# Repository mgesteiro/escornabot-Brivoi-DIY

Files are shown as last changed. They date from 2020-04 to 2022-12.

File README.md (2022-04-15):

# Escornabot Brivoi Audacius (DIY)
My own update to some parts of the [Escornabot project](https://github.com/escornabot) started during the COVID-19 lockdown.

* **[3D](3D/):** Inspired in the genius work and lessons from [Xoan](https://github.com/xoan?tab=repositories&q=escornabot), I updated the **Brivoi Audacius (or DIY)** models to the last version of [FreeCAD](https://freecadweb.org) (v0.19), using exclusively the **Part-Design workbench** and including some minor changes to suit my own personal needs and issues (that may be useful for others too).

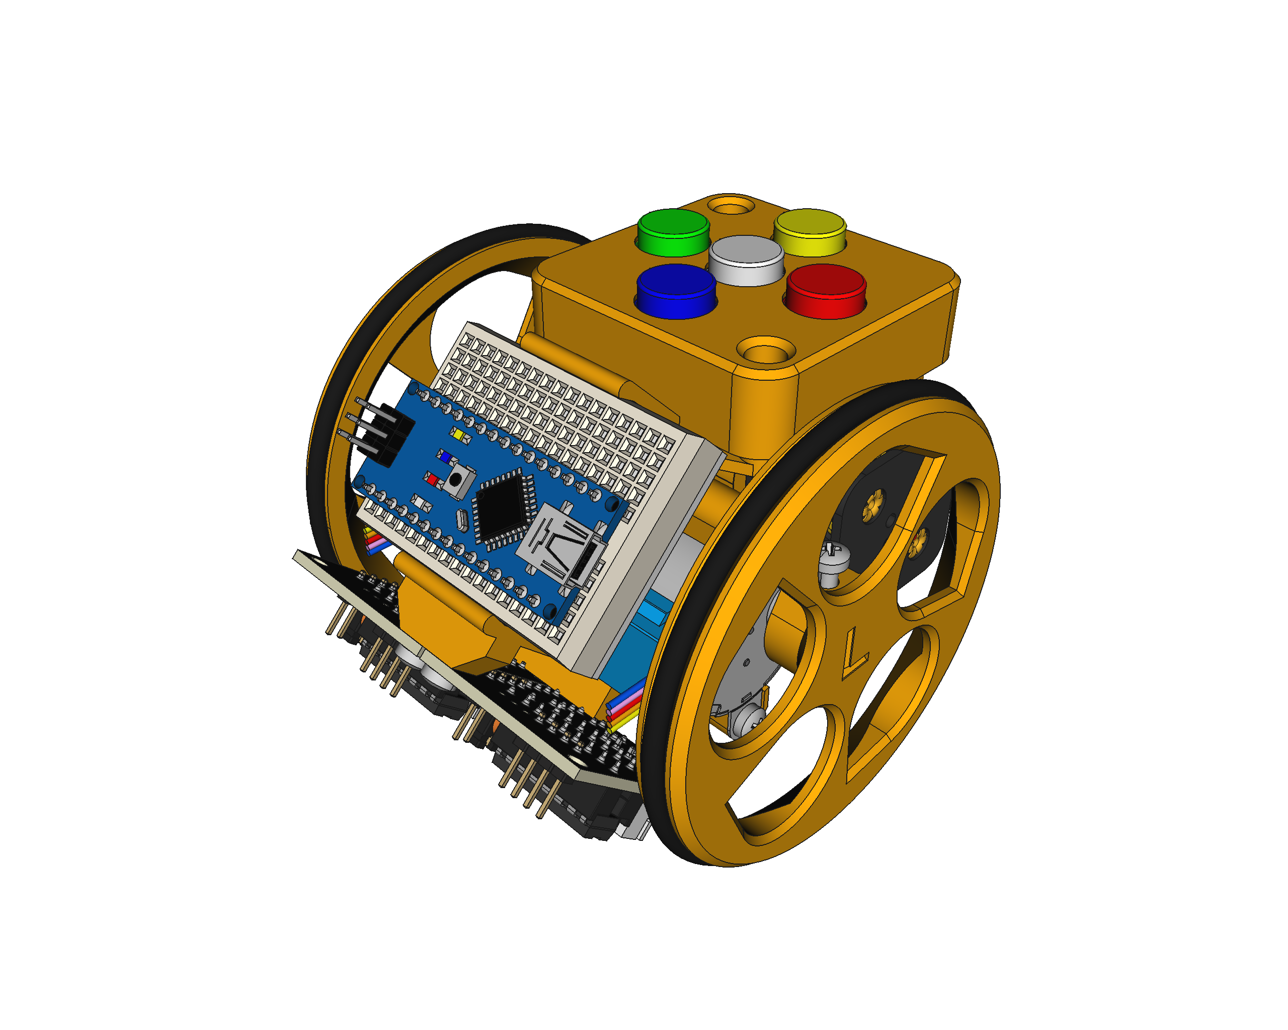
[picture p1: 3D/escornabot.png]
Escornabot
    

* **Electronics:** Everything related to the electronic part of the robot
    * **[Connections](electronics/connections/):** main schematic (done with [Fritzing](https://fritzing.org)).
    * **[Bluetooth Lower Energy](electronics/bluetooth/):** schematic, control App and firmware.

    Connections
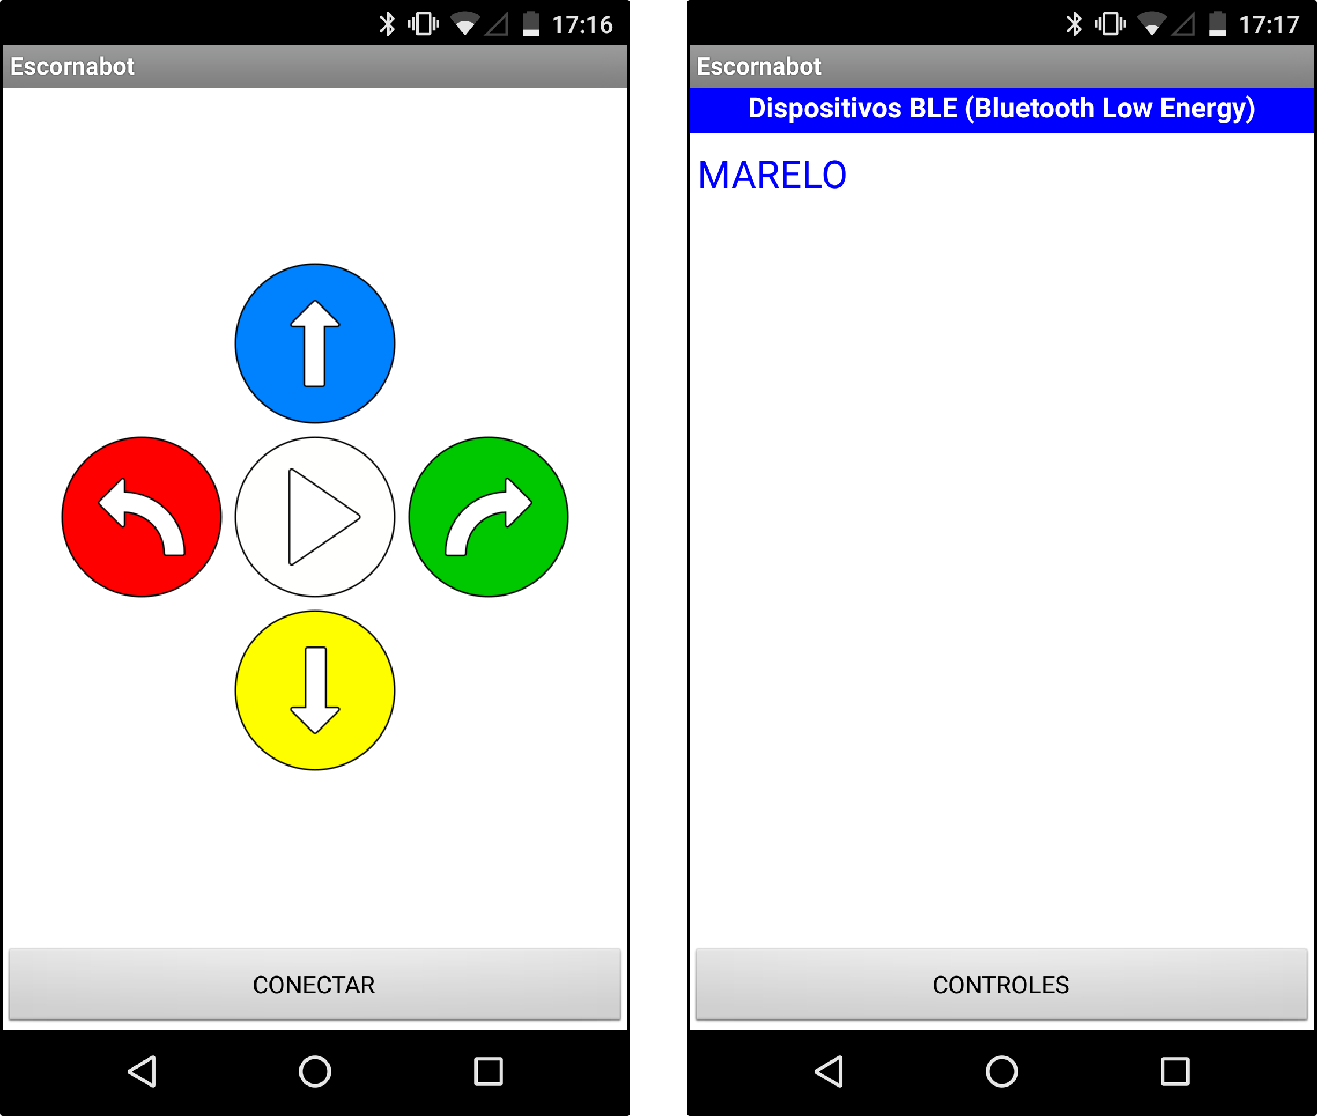
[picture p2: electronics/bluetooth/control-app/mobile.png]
BluetoothApp
    

## LICENSE

This work is licensed under the [GNU General Public License v3.0](LICENSE-GPLV30). All media and data files that are not source code are licensed under the [Creative Commons Attribution 4.0 BY-SA license](LICENSE-CCBYSA40).

More information about licenses in [Opensource licenses](https://opensource.org/licenses/) and [Creative Commons licenses](https://creativecommons.org/licenses/).

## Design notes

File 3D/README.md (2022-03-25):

# Escornabot Brivoi-DIY - 3D models

Updated 3D models of the **Escornabot Brivoi-DIY** to the last version of [FreeCAD](https://freecadweb.org) (v0.19), using exclusively the **Part-Design workbench** and including some minor changes to suit my own personal needs and issues (explained below), that may be useful to others too.

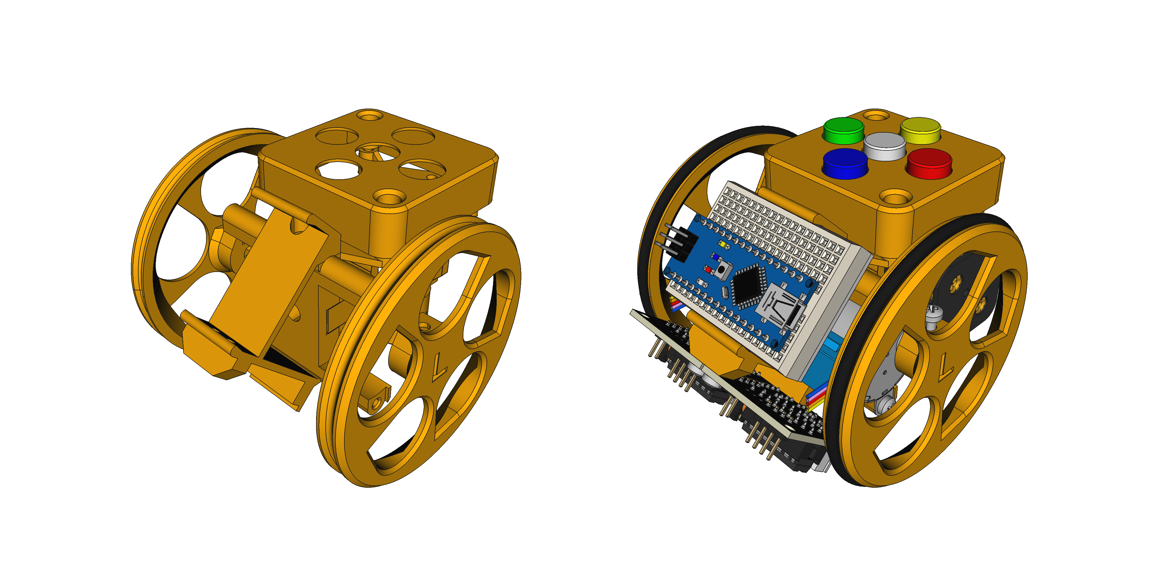
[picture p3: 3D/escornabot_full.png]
Escornabot

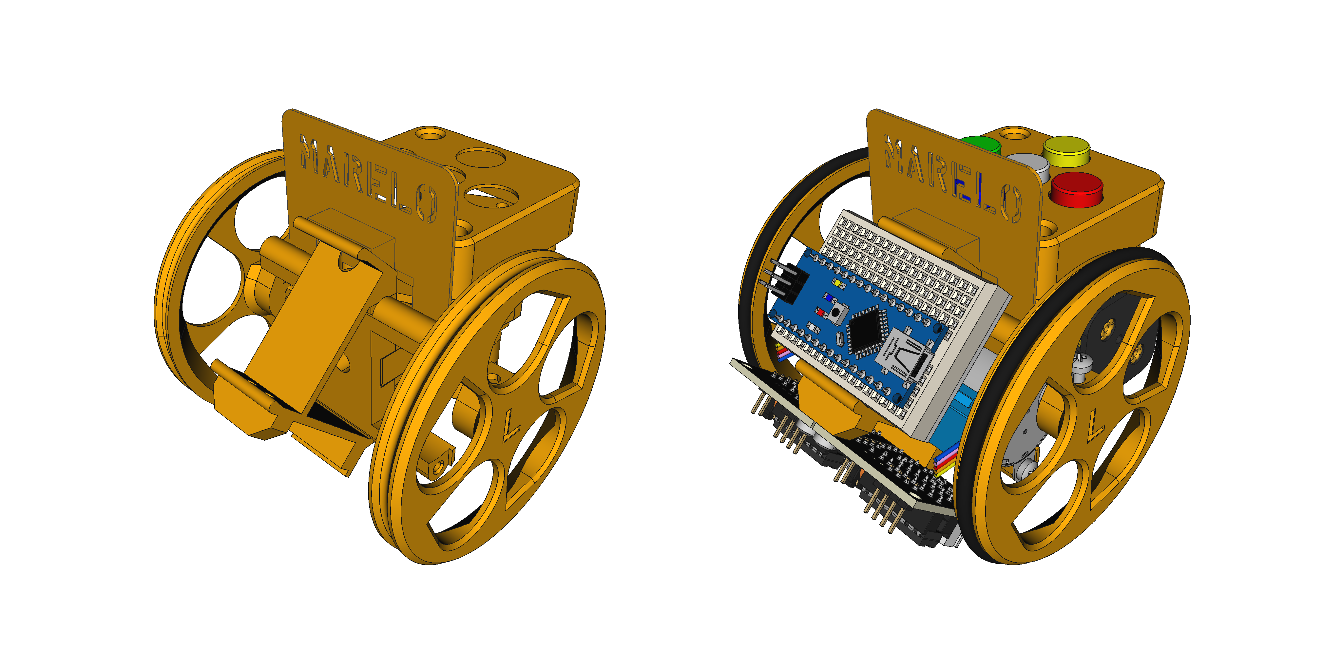
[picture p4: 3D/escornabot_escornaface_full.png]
Escornabot


* Now with a full assembly file (for the [Assembly4 FreeCAD workbench](https://wiki.freecadweb.org/Assembly4_Workbench)): **[escornabot.FCStd](escornabot.FCStd)**
* Additional non printable 3D parts in the `parts` folder
* STL files already generated and ready to use

### Battery bracket
New v-shaped joint for the motor bracket (borrowed from [Xoan](https://github.com/xoan?tab=repositories&q=escornabot)). Added configuration params to better fit different battery holder dimensions as I've found important differences.
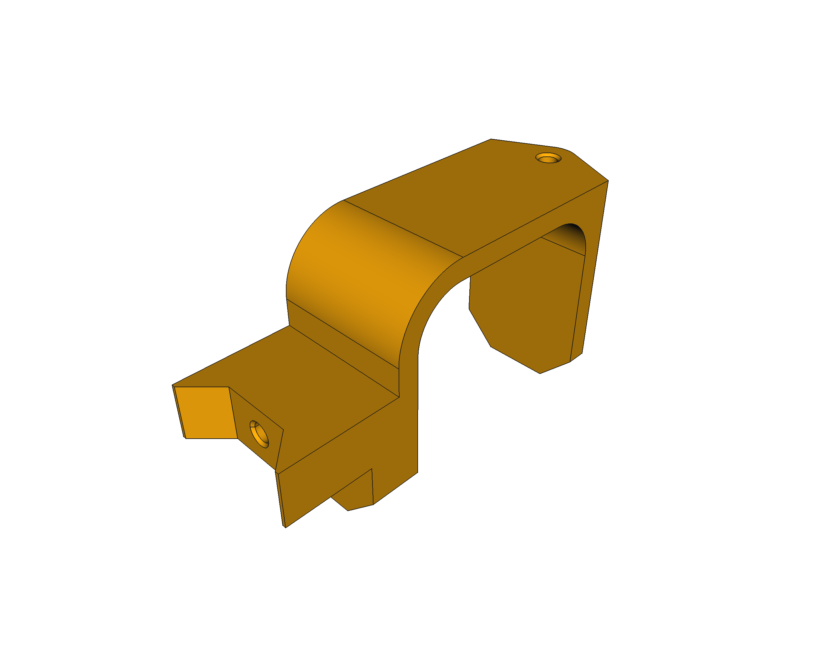
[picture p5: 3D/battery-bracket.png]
battery-bracket


### Motor bracket
Updated connection joint to the battery bracket: easier, simpler and more robust. Additional support for the stepper motor tabs.
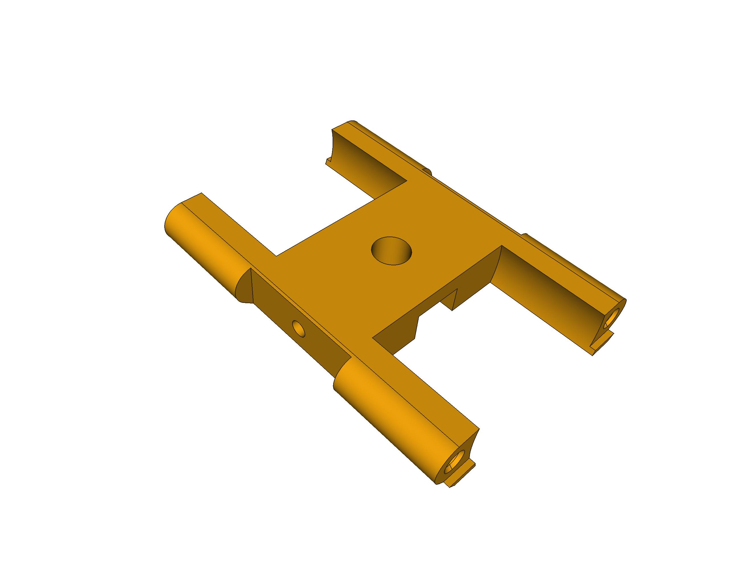
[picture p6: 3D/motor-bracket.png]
motor-bracket


### Keypad holder
Thinner. Added estructural support for the screw holders: easier to print and more robust.
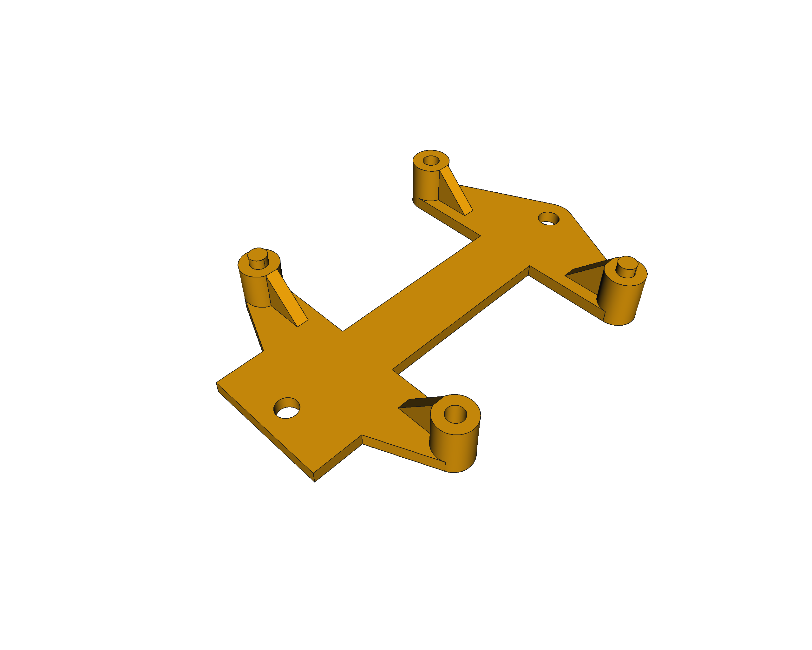
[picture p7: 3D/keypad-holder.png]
keypad-holder


### Board bracket
Converted to Part-Design workbench and updated supports for the stepper driver boards that should not move now.

* MiniBread Board 170 contacts by Robotdyn **without notches** (not available anymore)
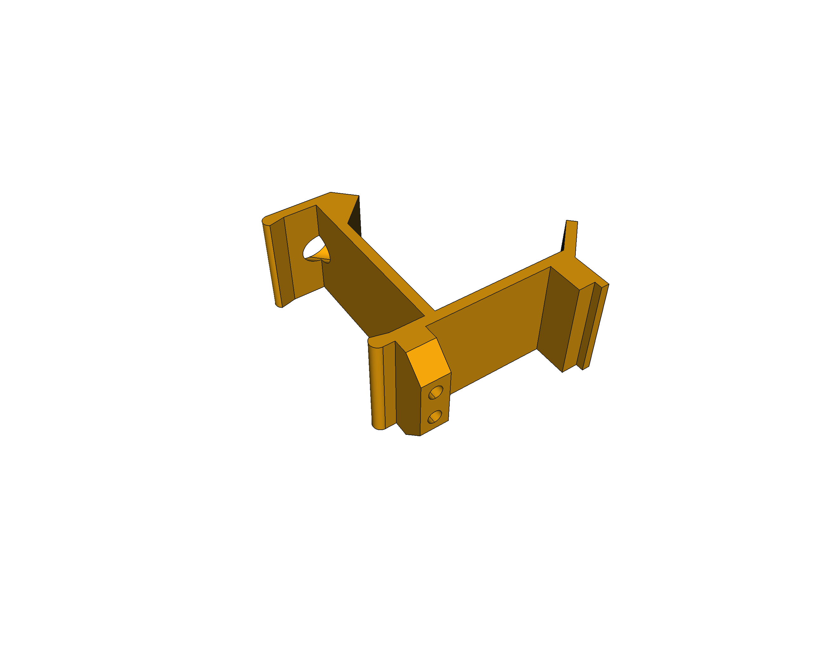
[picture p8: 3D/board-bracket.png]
board-bracket
	

* MiniBread Board 170 contacts with notches (more common)
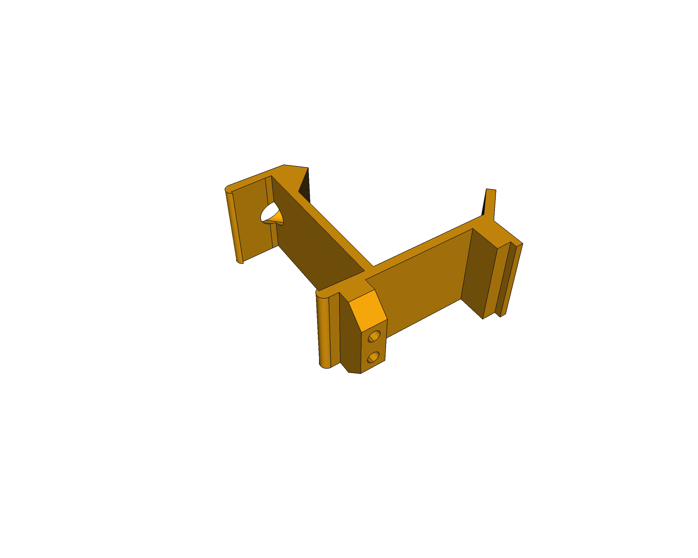
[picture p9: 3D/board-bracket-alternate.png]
board-bracket-alternate
	

### Ball caster and Ball caster battery
Added configuration params (e.g. ball diameter) and converted to Part-Design workbench.
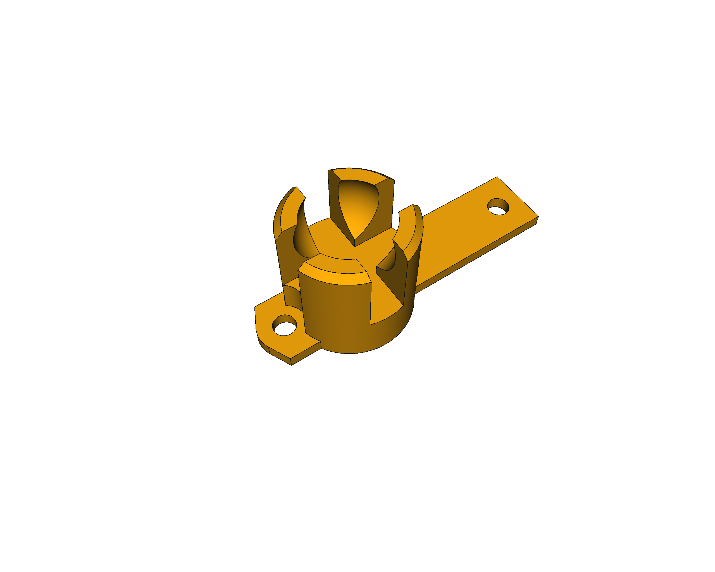
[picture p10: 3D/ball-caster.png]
ball-caster


With support for fifth HR06/AA 1.2V NiMH battery
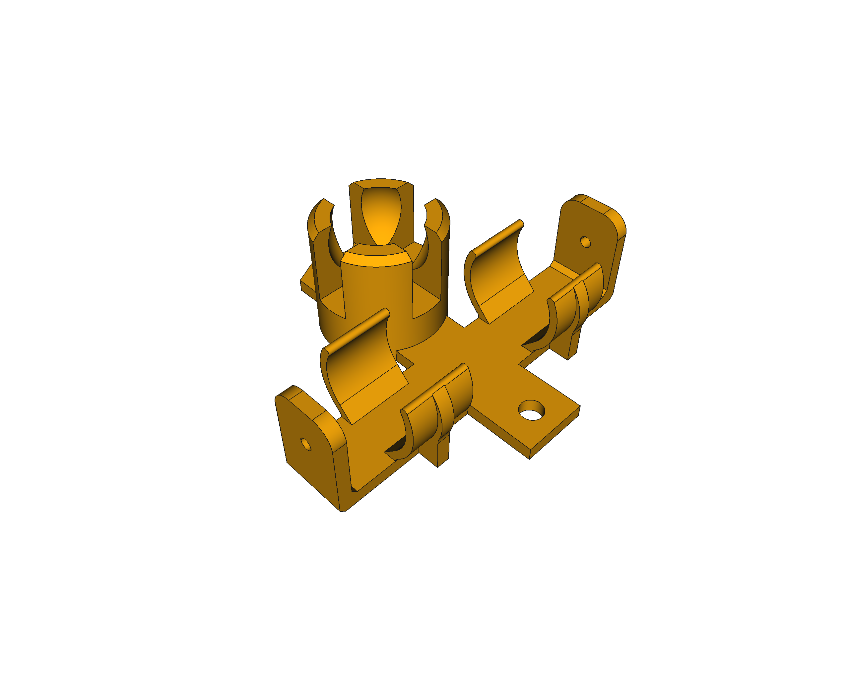
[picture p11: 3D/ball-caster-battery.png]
ball-caster-battery


### Switch holder
Converted to Part-Design workbench and redesigned.
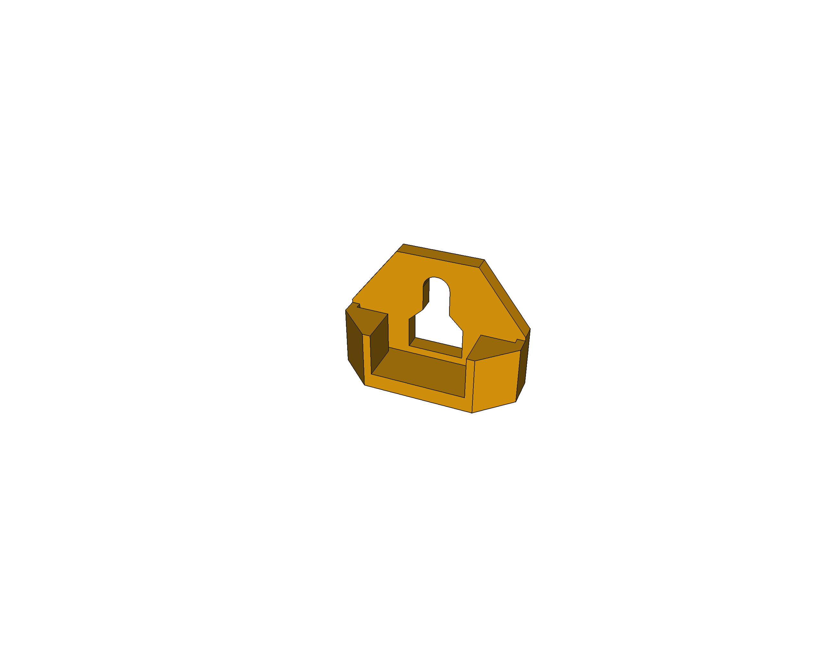
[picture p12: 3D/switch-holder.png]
switch-holder


### Wheels
Circular bed for the o-ring (no more "v"). Updated "L" and "R" letters and dimensions of some of the holes. Converted to Part-Design only. Available [base wheel](wheel-base.FCStd) ready to be customized.
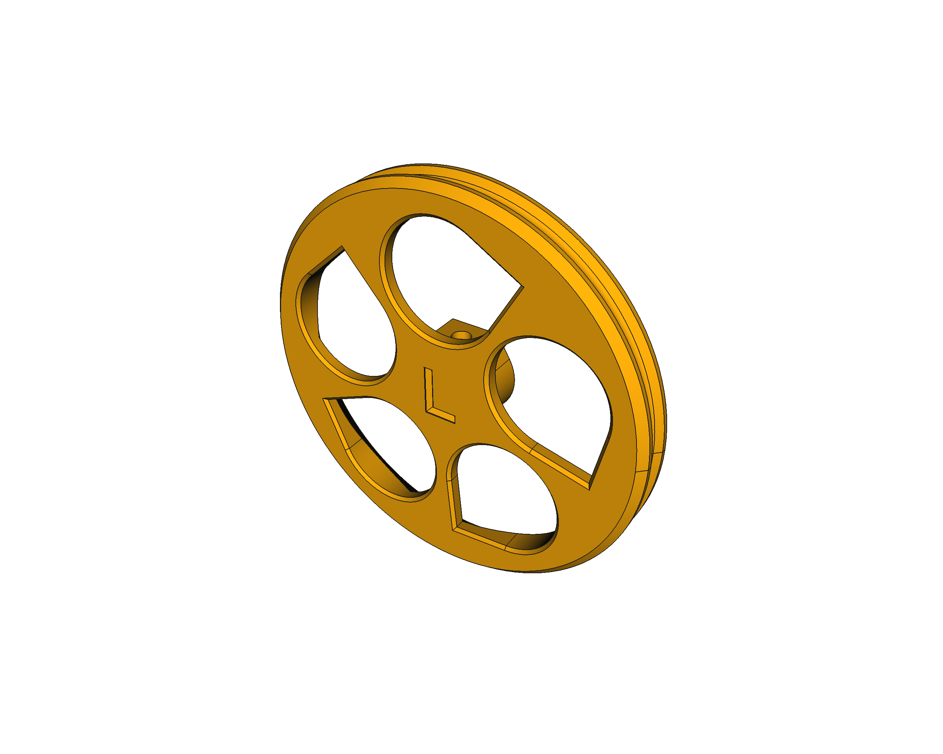
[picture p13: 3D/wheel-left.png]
wheel-left

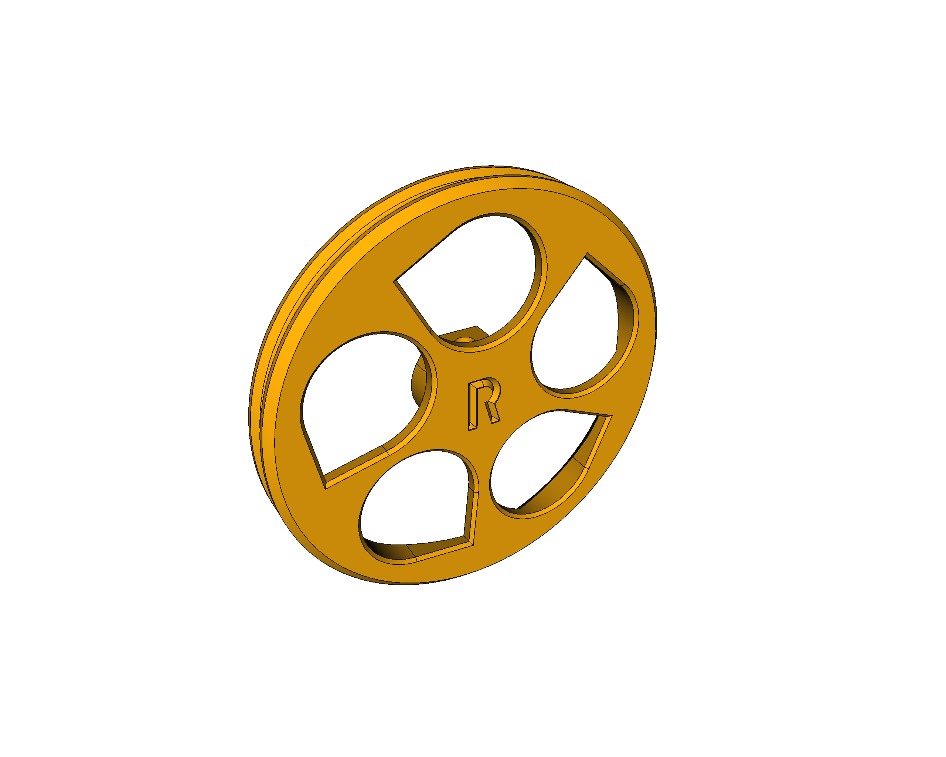
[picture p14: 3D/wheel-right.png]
wheel-right


### Keypad cover
This one is new, for [my own Ki-CAD keyboard](https://github.com/mgesteiro/escornakeypad) with B3F-40xx buttons and caps. Round corners, finally!
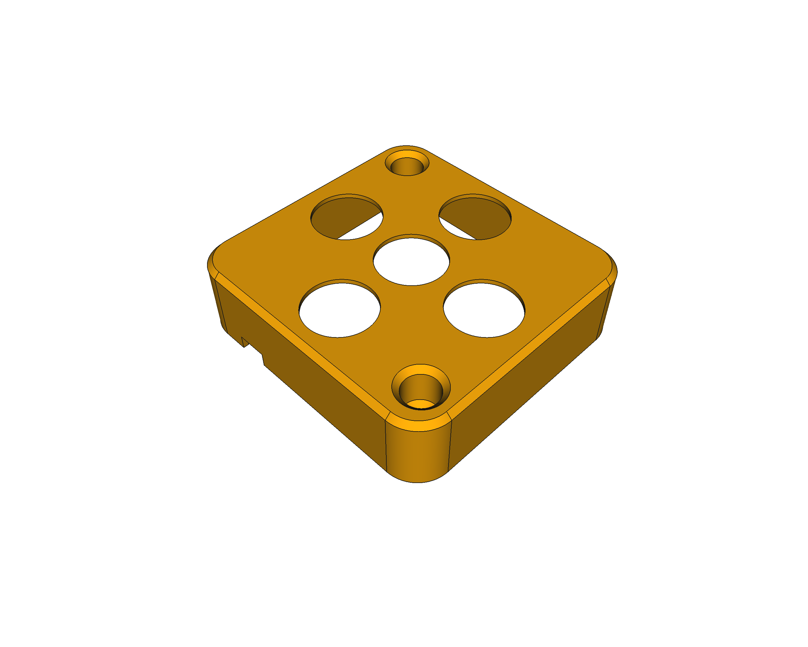
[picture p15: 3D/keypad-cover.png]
keypad-cover


## Extras
I made a couple of extra models:

### Escornaface
A piece to customize your Escornabot: put your name (or whatever you want).
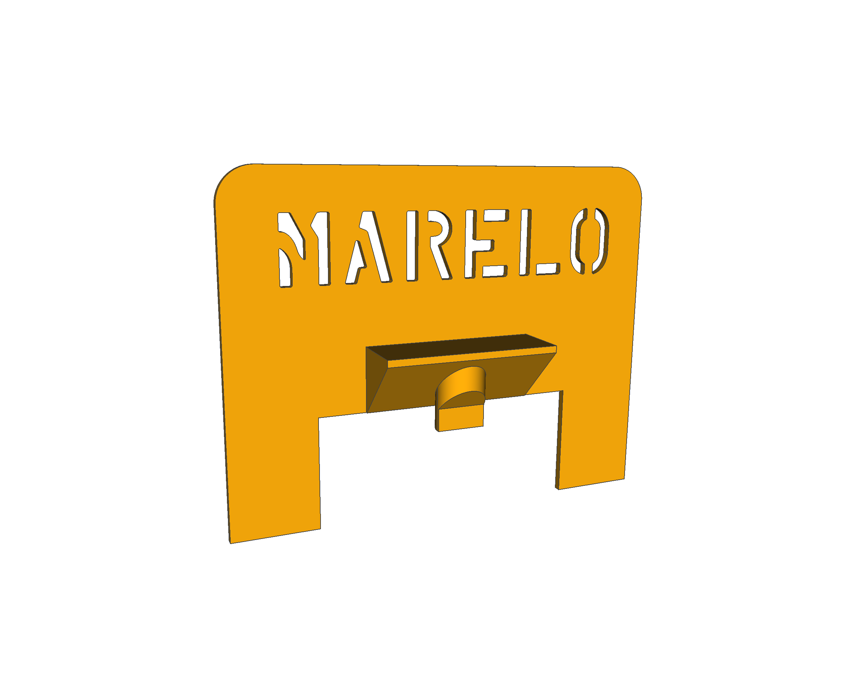
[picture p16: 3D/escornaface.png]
escornaface


### Battery bracket *Escornabot Pintor Kit*
A battery holder with pre-drilled holes to support the [Escornabot Pintor Kit](https://github.com/einsua/Escornabot_Pintor_Kit)
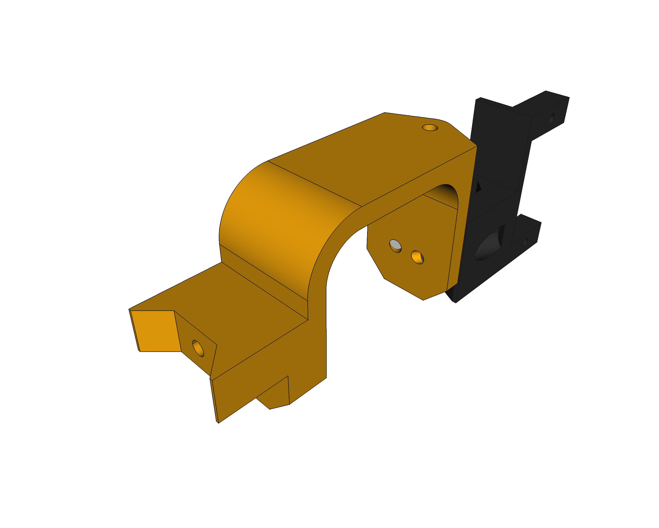
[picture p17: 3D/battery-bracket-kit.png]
battery-bracket-kit


### Ogaki CPU holder
In case you have an Abierto's Ogaki Escornabot: use instead of the **keypad holder** and **board bracket**.
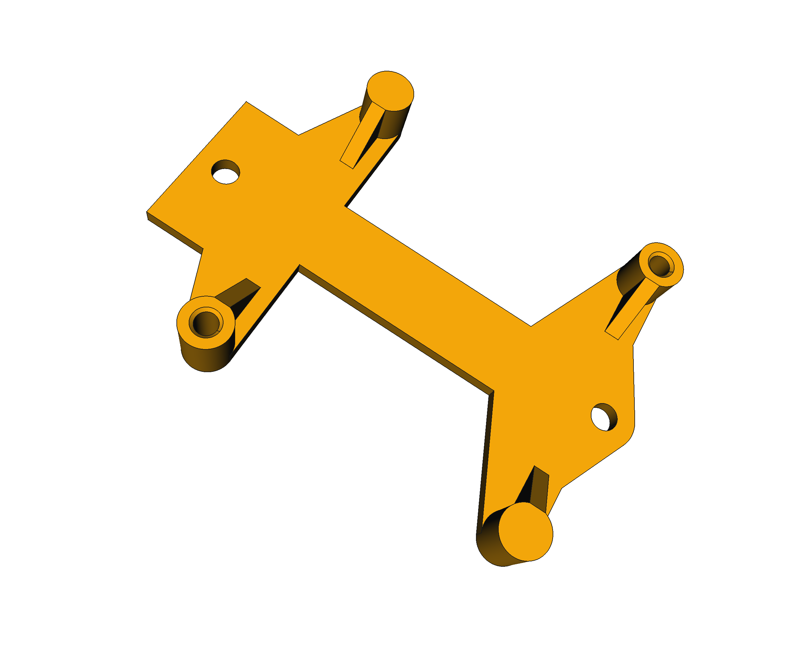
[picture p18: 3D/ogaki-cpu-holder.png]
ogaki-cpu-holder


## LICENSE

This work is licensed under the [GNU General Public License v3.0](../LICENSE-GPLV30). All media and data files that are not source code are licensed under the [Creative Commons Attribution 4.0 BY-SA license](../LICENSE-CCBYSA40).

More information about licenses in [Opensource licenses](https://opensource.org/licenses/) and [Creative Commons licenses](https://creativecommons.org/licenses/).

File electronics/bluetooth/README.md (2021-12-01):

# Escornabot Brivoi-DIY - Bluetooth Low Energy (BLE)
Providing **Bluetooth Low Energy** connectivity to the **Escornabot Brivoi-DIY** using an [**HM-10 BLE dongle**](https://www.aliexpress.com/wholesale?SearchText=HM-10+arduino).

## CONNECTIONS / SCHEMATIC
These are the six additional connections required for the [main basic schematic](../connections/) (done with [Fritzing](https://fritzing.org)):

schematic

* **R1** and **R2** resistors conform a voltage divider to adapt Arduino's 5V TX ttl output levels to those 3.3V of the **HM-10 BLE dongle**.
* The pink wire/jumper is **under the Arduino Nano**, to extend the GND connection to the first low column of the protobard, where the **R1** resistor is connected.

## ENABLING Bluetooth
If you want to use *Bluetooth connectivity* in your **Escornabot**, please make sure that **it is ENABLED** in its firmware: before [compiling and uploading it](https://www.roboteach.es/escornabot-firmware/) edit the `Configuration.h` file and make sure that this line is enabled (=`true`) like this:

`#define USE_BLUETOOTH true`

## CONTROL APP
Once you have the dongle installed in your **Escornabot** and the *Bluetooth connectivity* enabled, you need *something* to send commands to it. This is usually an *App* that you can install in your smartphone or tablet.

If you have an **Android system** (smartphone/tablet) you can use our own open-source [**Escornabot app APK**](control-app/Escornabot.apk) (more info available in the [`control-app`](control-app/) folder).

Android Mobile App

For **iOS systems** you can use the [Escornabot BLE app](https://apps.apple.com/es/app/escornabot-ble/id1444892609), that is also open-source and available on [Ismael Serrano's github](https://github.com/ismaserrano/EscornaBotMobile).

Finally, if you like to tinker yourself, you can use **any BLE App, Escanner or tool** that allows you to connect and send characters to the dongle: you should send any of the `[n, w, g, e, s, N, W, G, E, S]` characters followed by a line feed (`LF` or `\n`) as commands (**n**orth, **s**outh, **e**ast, **w**est and **g**o).

## RENAME YOUR DONGLE
If you want to rename your dongle/robot you can use the Arduino sketch found in the [`rename`](rename/) folder: open it with the Arduino IDE and follow the instructions.

## LICENSE

This work is licensed under the [GNU General Public License v3.0](../LICENSE-GPLV30). All media and data files that are not source code are licensed under the [Creative Commons Attribution 4.0 BY-SA license](../LICENSE-CCBYSA40).

More information about licenses in [Opensource licenses](https://opensource.org/licenses/) and [Creative Commons licenses](https://creativecommons.org/licenses/).

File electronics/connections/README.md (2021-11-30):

# Escornabot Brivoi-DIY - connections

Main electronics connection schematic for the **Escornabot Brivoi-DIY**, done with [Fritzing](https://fritzing.org).

Connections

It uses some Fritzing parts available [here](https://github.com/mgesteiro/fritzing-parts). This assembly is based on my analog keypad, that is published [here](https://github.com/mgesteiro/escornakeypad).

## LICENSE

This work is licensed under the [GNU General Public License v3.0](../LICENSE-GPLV30). All media and data files that are not source code are licensed under the [Creative Commons Attribution 4.0 BY-SA license](../LICENSE-CCBYSA40).

More information about licenses in [Opensource licenses](https://opensource.org/licenses/) and [Creative Commons licenses](https://creativecommons.org/licenses/).

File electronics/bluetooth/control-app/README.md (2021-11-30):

# Escornabot Brivoi-DIY - Bluetooth Low Energy (BLE) Android control App

This is an open-source **Bluetooth Low Energy control App** for the **Escornabot Brivoi-DIY** using an [**HM-10 BLE dongle**](https://www.aliexpress.com/wholesale?SearchText=HM-10+arduino) that you can [connect to the **Escornabot**](..) itself.

As it's **open-source** it's public, available and free to use:

  * The **Escornabot** app compiled APK ready to install: [Escornabot.apk](Escornabot.apk)
  * The **Escornabot** app *AppInventor* source code: [Escornabot.aia](Escornabot.aia)

Android Mobile App

This app has been developed and generated using the [MIT App Inventor system](http://appinventor.mit.edu/), a platform that enables you to create *Android mobile Apps* using its **Graphical Designer and Visual Blocks language IDE**.

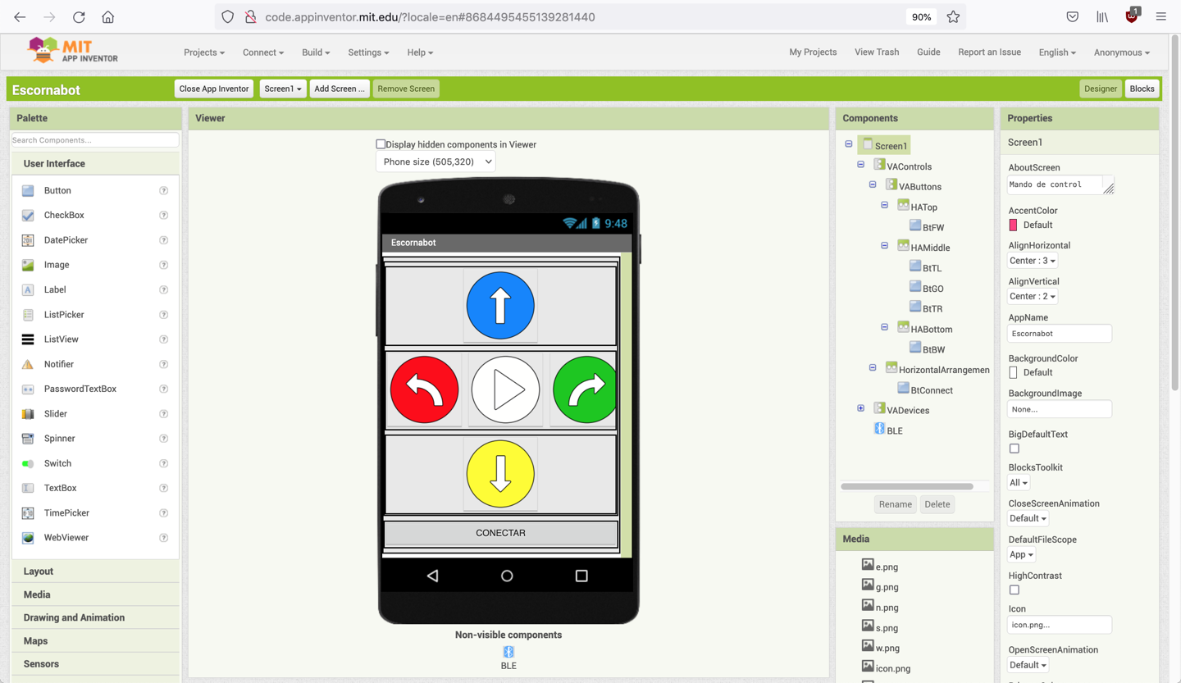
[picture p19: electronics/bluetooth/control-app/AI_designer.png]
AppInventor Designer

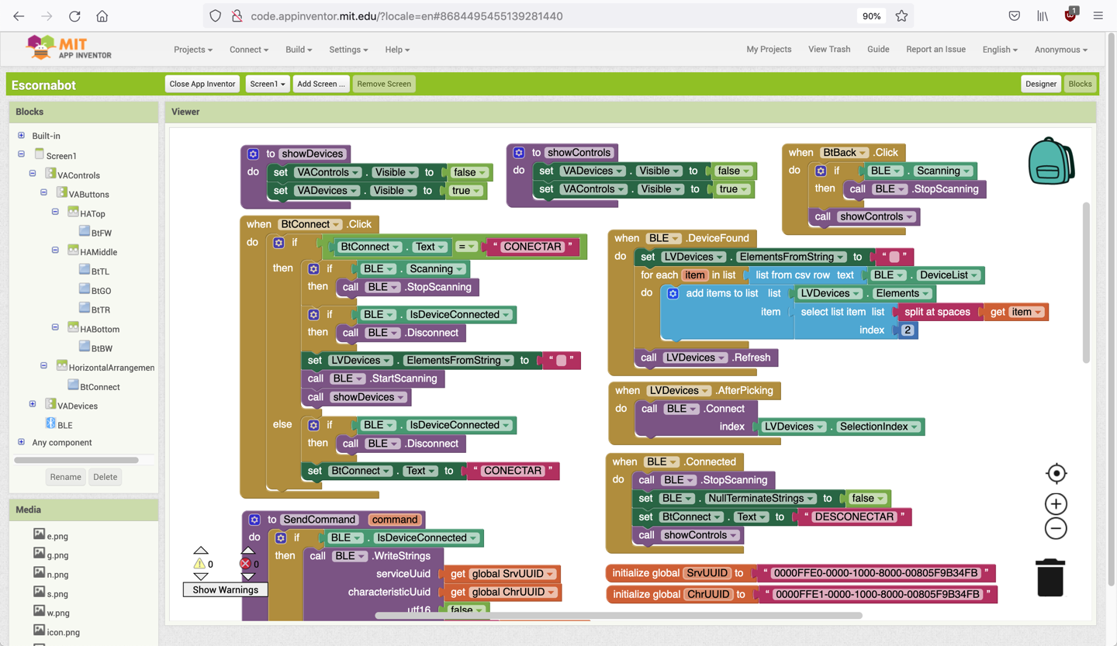
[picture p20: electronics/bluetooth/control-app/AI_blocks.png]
AppInventor Blocks


For **iOS systems** you can use the [Escornabot BLE App](https://apps.apple.com/es/app/escornabot-ble/id1444892609), that is also open-source and available on [Ismael Serrano's github](https://github.com/ismaserrano/EscornaBotMobile).

Finally, if you like to tinker yourself, you can use **any BLE App, Escanner or tool** that allows you to connect and send characters to the dongle: you should send any of the `[n, w, g, e, s, N, W, G, E, S]` characters followed by a line feed (`LF` or `\n`) as commands (**n**orth, **s**outh, **e**ast, **w**est and **g**o).

## LICENSE

This work is licensed under the [GNU General Public License v3.0](../LICENSE-GPLV30). All media and data files that are not source code are licensed under the [Creative Commons Attribution 4.0 BY-SA license](../LICENSE-CCBYSA40).

More information about licenses in [Opensource licenses](https://opensource.org/licenses/) and [Creative Commons licenses](https://creativecommons.org/licenses/).

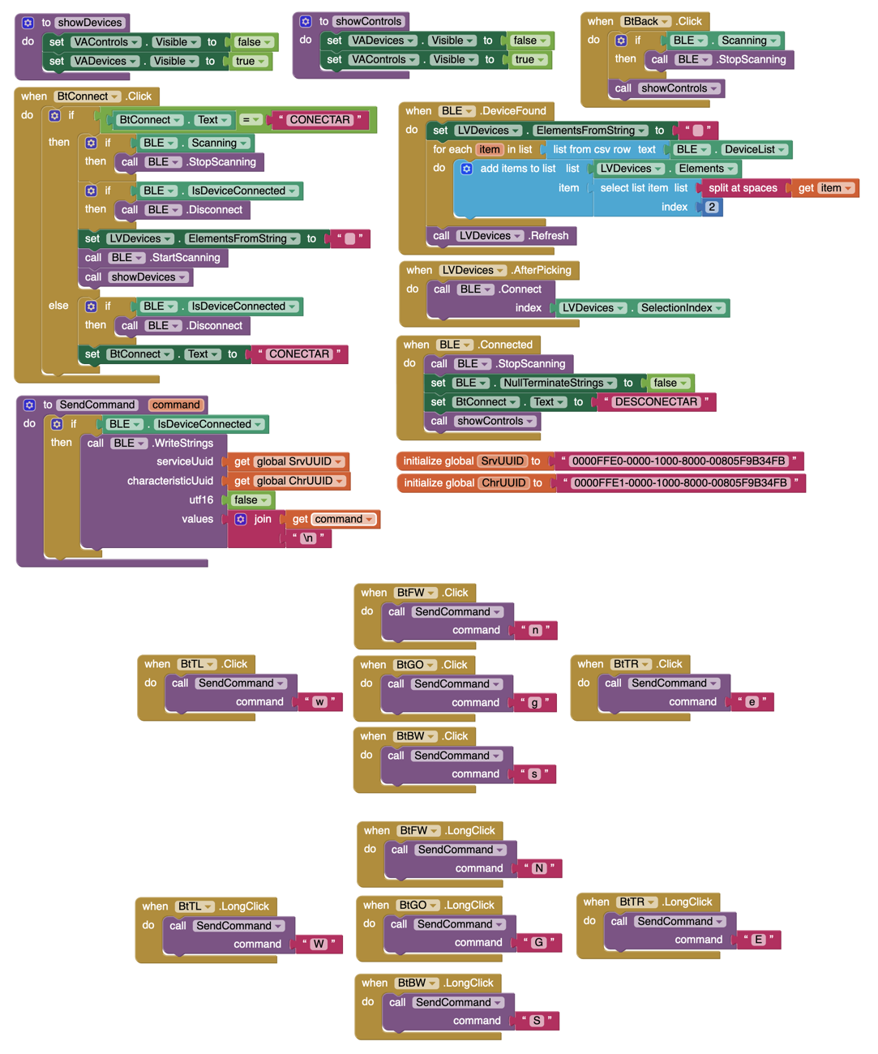
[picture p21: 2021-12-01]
electronics/bluetooth/control-app/Escornabot.aia.png

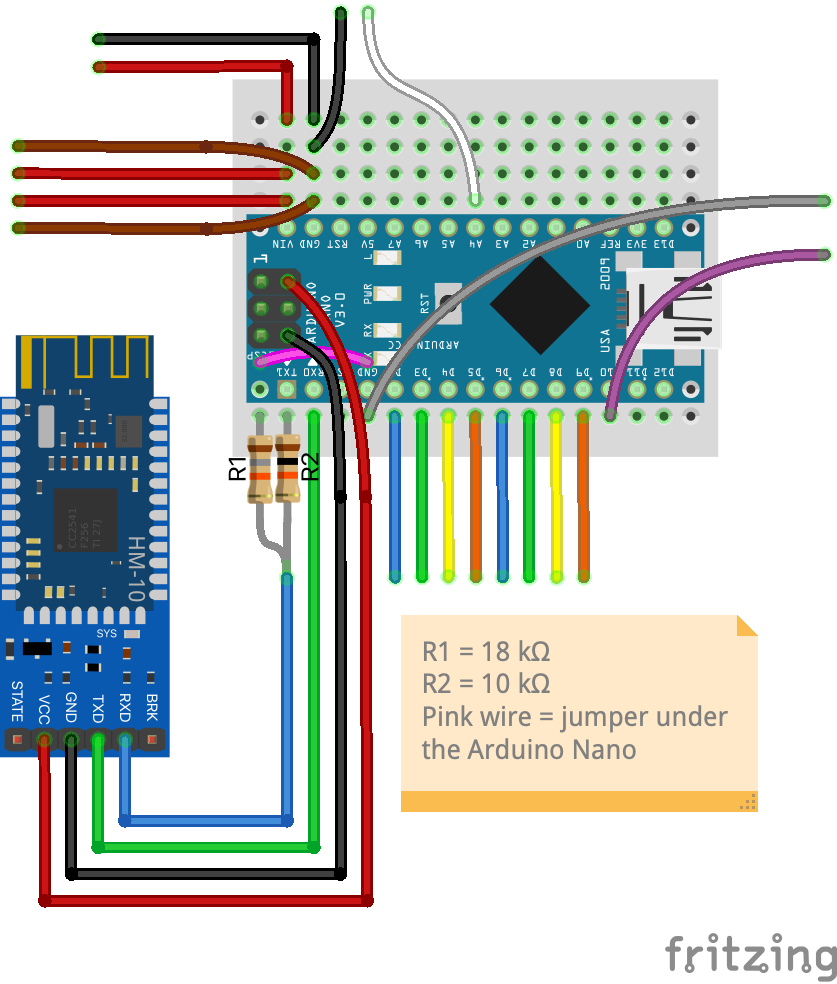
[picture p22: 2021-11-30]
electronics/bluetooth/bluetooth_bb.png

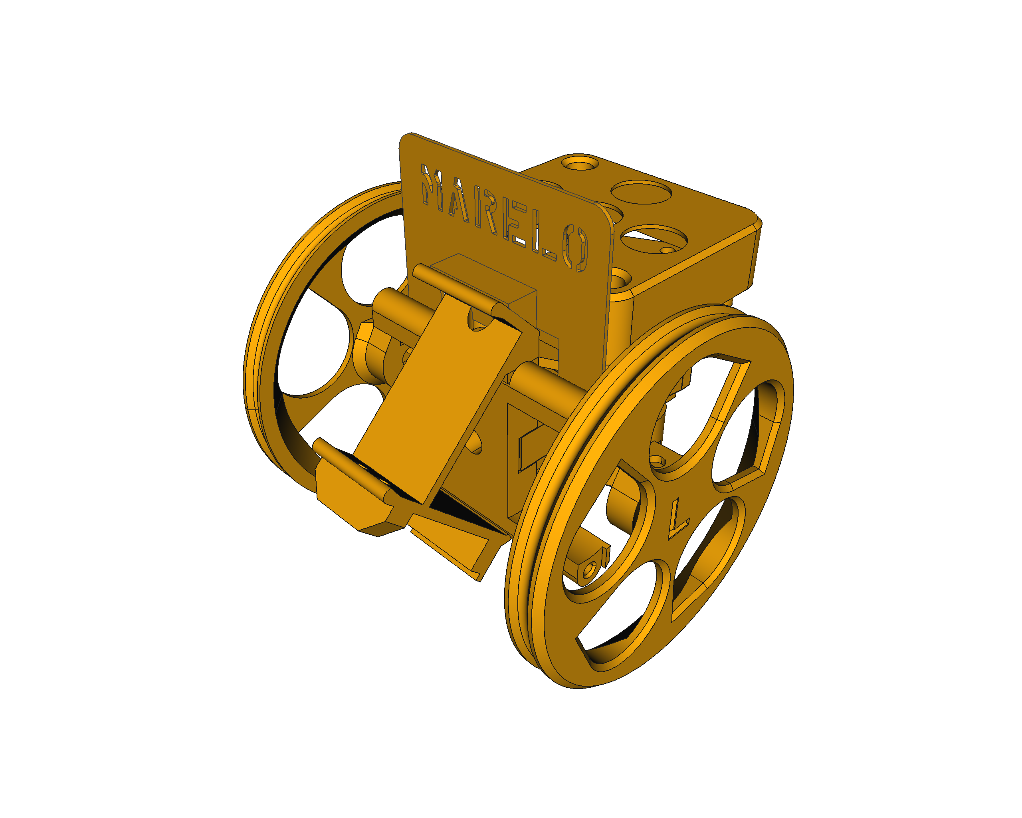
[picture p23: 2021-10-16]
3D/escornabot-escornaface-nude.png

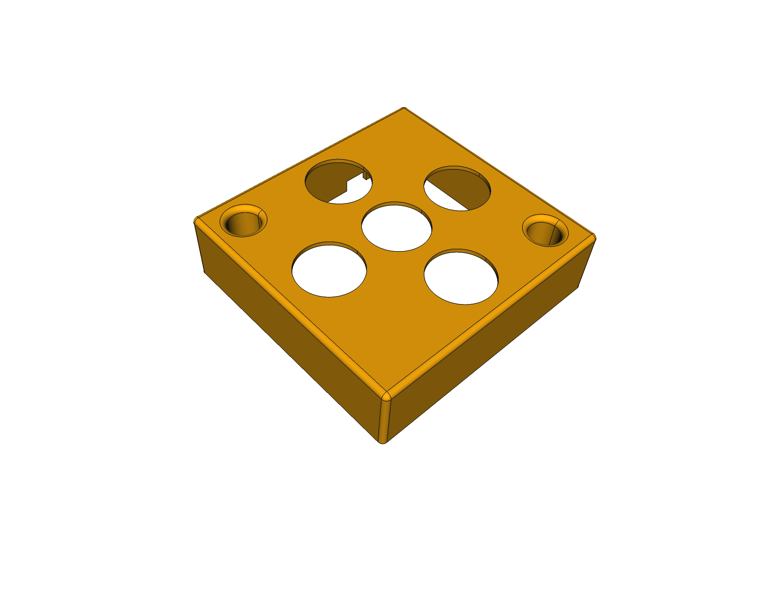
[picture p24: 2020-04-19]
3D/keypad-cover-sq.png

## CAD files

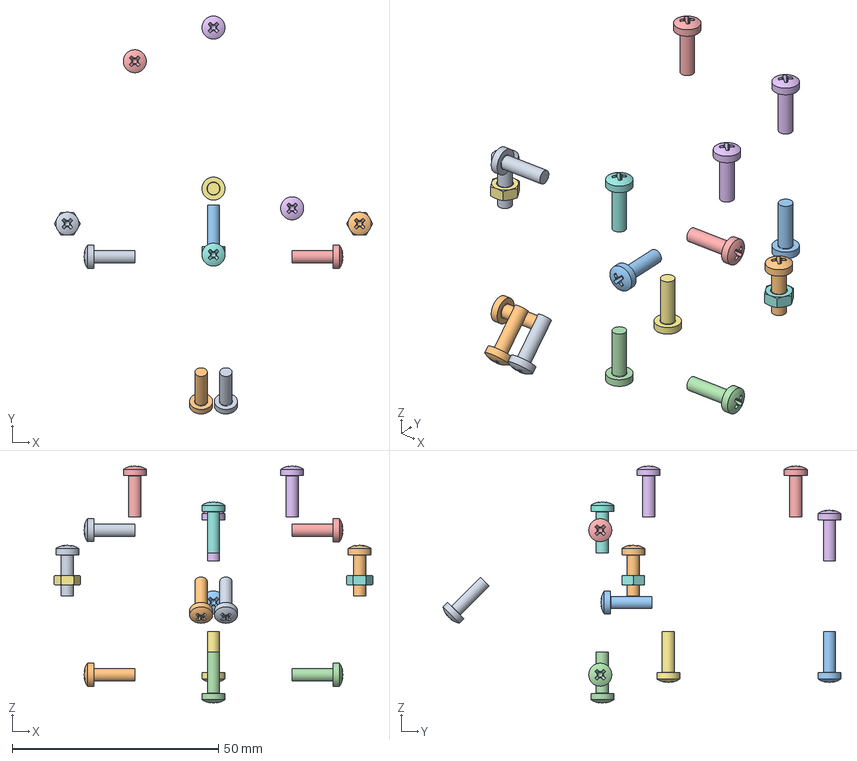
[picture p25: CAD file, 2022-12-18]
3D/escornabot.FCStd
77.2 x 96.4 x 57.4 mm
M3x10-Screw544 x 2
M3x10-Screw545 x 2
M3x10-Screw x 2
M3x10-Screw546 x 2
M3x10-Screw547 x 2
M3x10-Screw524 x 2
M3x10-Screw525 x 2
M3x10-Screw526 x 2
M3x10-Screw535 x 2
M3x10-Screw536 x 2
M3x10-Screw550 x 2
M3x10-Screw551 x 2
M3x10-Screw531 x 2
M3x10-Screw532 x 2
M3-Nut x 2
M3-Nut001 x 2
M3x10-Screw548 x 2
M3x10-Screw549 x 2

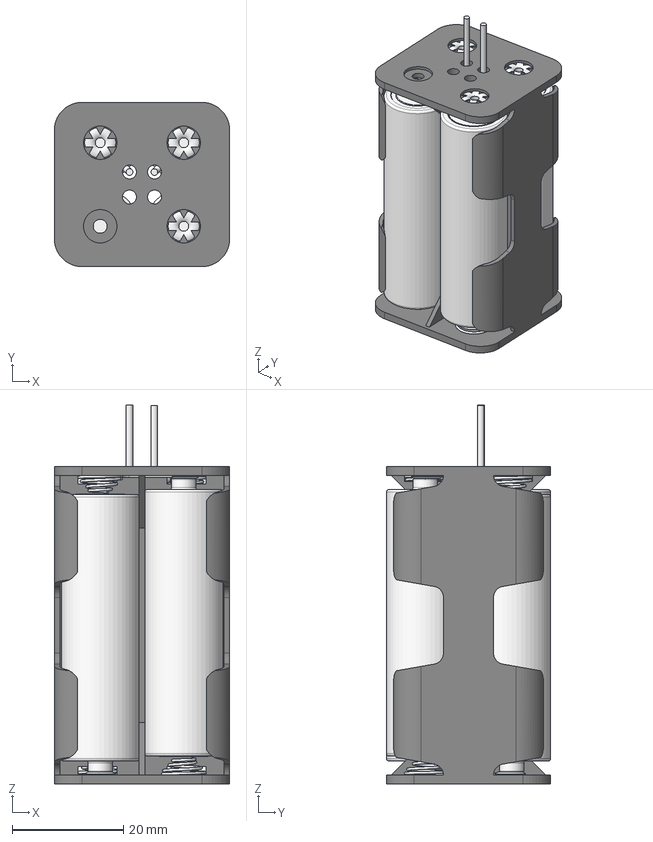
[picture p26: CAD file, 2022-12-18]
3D/parts/battery-holder-2x2.FCStd
31.5 x 29.5 x 68.1 mm
pila04
pila03
pila02
pila01
cuerpo
remaches
muelles
cable-R
cable-N

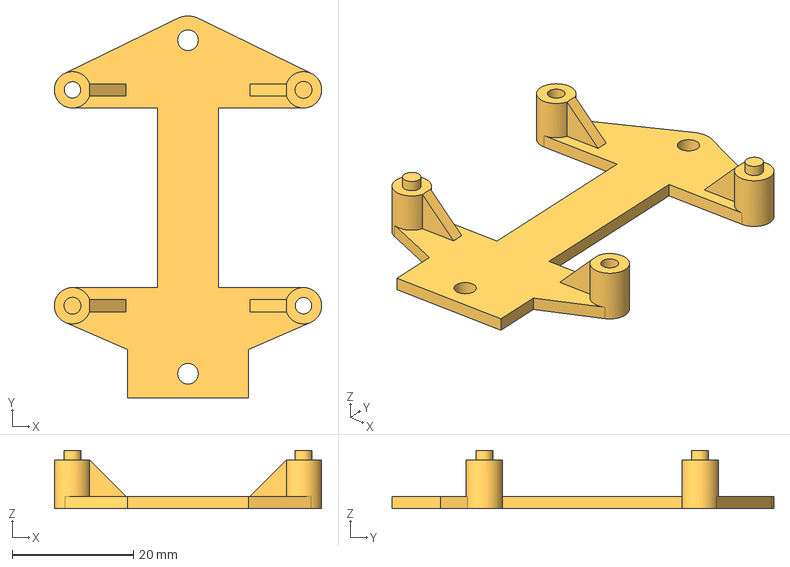
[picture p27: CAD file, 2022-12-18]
3D/keypad-holder.FCStd
44.1 x 63.0 x 9.60 mm

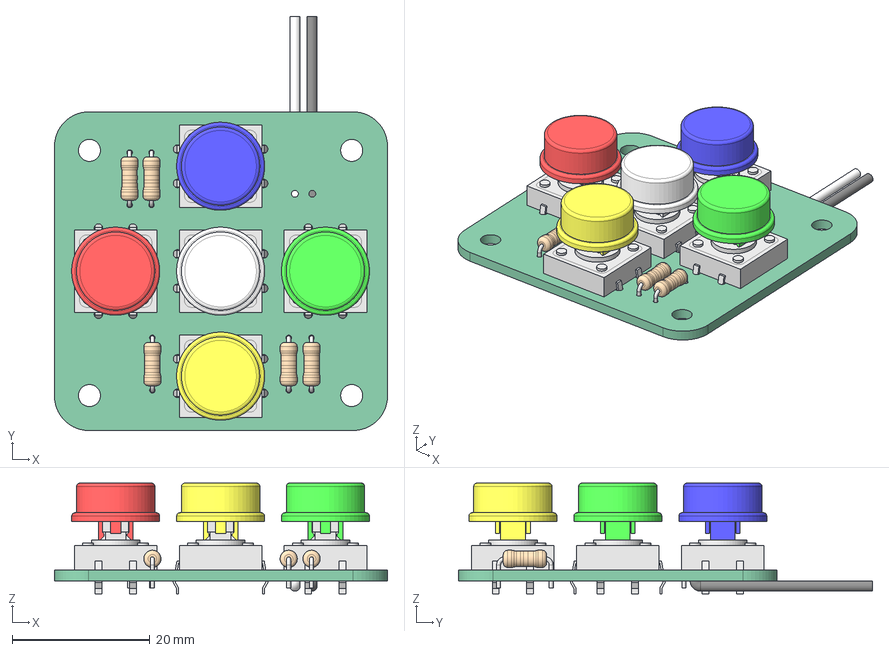
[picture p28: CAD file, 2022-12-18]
3D/parts/keypad.FCStd
48.4 x 60.1 x 16.1 mm
Pcb
10k
wire
10k001
wire001
10k002
wire002
10k003
wire003
10k004
wire004
S5_B3F-4050
S4_B3F-4050
S3_B3F-4050
S1_B3F-4050
S2_B3F-4050
keycap
keycap1
keycap2
keycap3
keycap4
cable-W
cable-N

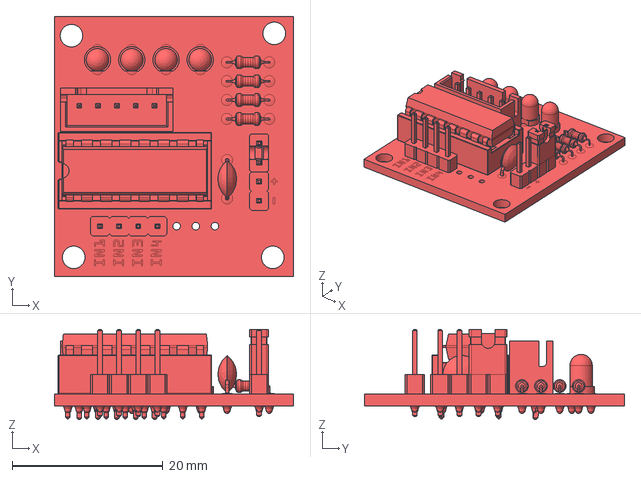
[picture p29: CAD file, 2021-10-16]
3D/parts/driver-board.FCStd
31.7 x 34.5 x 11.9 mm

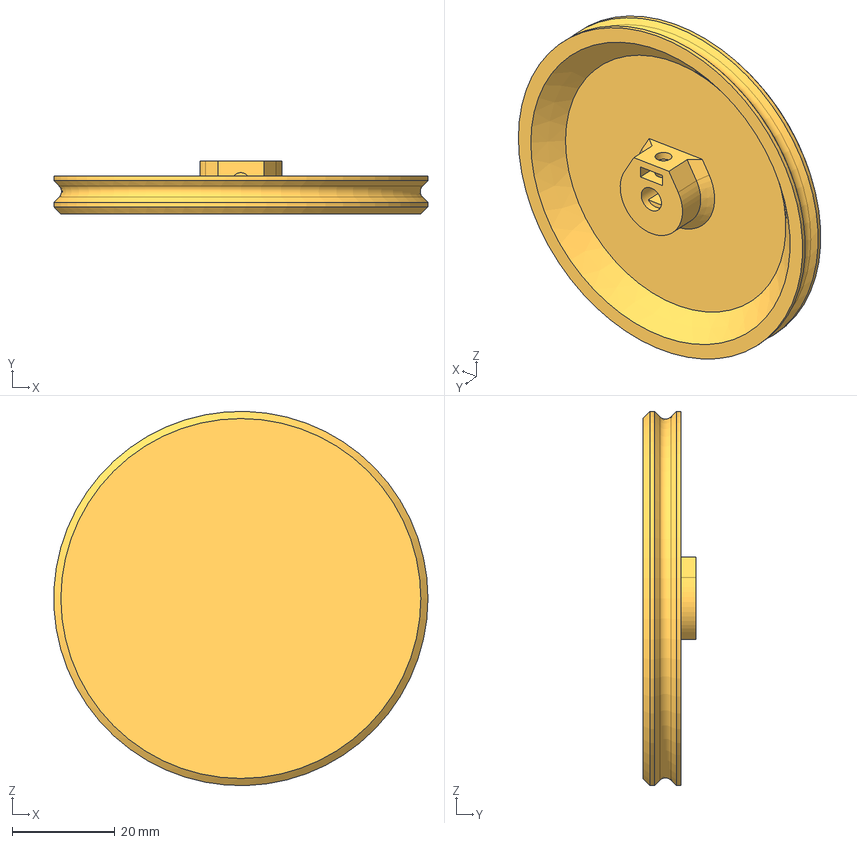
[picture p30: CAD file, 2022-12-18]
3D/wheel-base.FCStd
72.9 x 10.4 x 73.0 mm

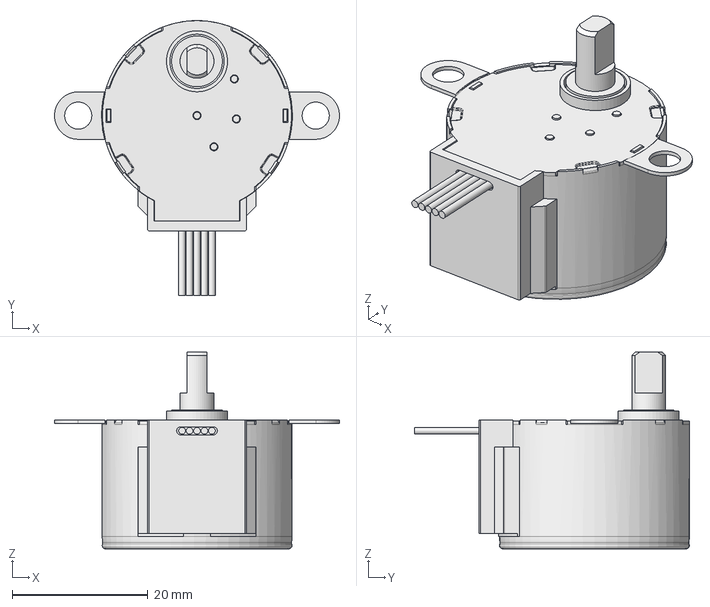
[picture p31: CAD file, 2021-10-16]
3D/parts/28BYJ-48.FCStd
42.0 x 40.5 x 29.0 mm

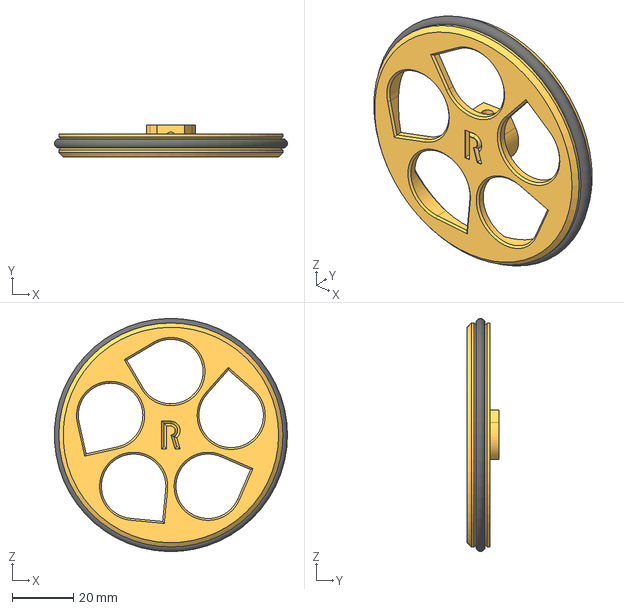
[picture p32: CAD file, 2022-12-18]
3D/wheel-right.FCStd
75.9 x 10.4 x 76.0 mm
Body-wheel-right
o-ring-R

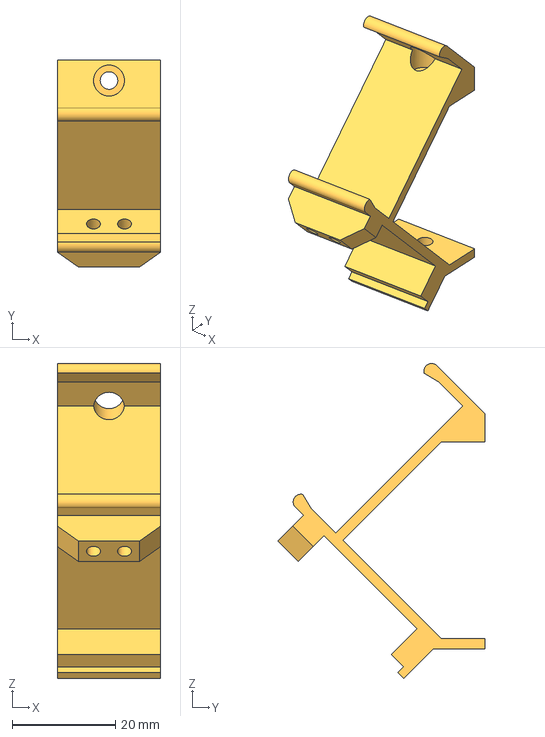
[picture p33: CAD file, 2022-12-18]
3D/board-bracket.FCStd
20.0 x 40.1 x 60.9 mm

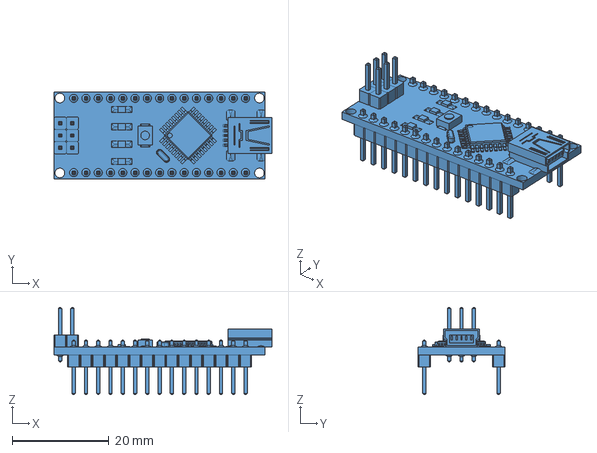
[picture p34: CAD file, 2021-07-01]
3D/parts/nano-v3.FCStd
45.1 x 17.9 x 18.0 mm

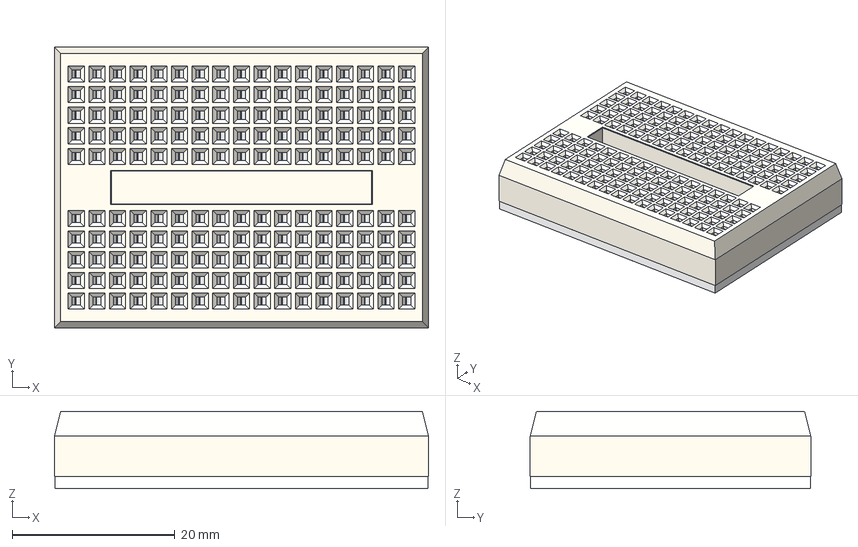
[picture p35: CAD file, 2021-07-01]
3D/parts/mini-breadboard.FCStd
46.0 x 34.5 x 9.50 mm
cuerpo
almohadilla
railes

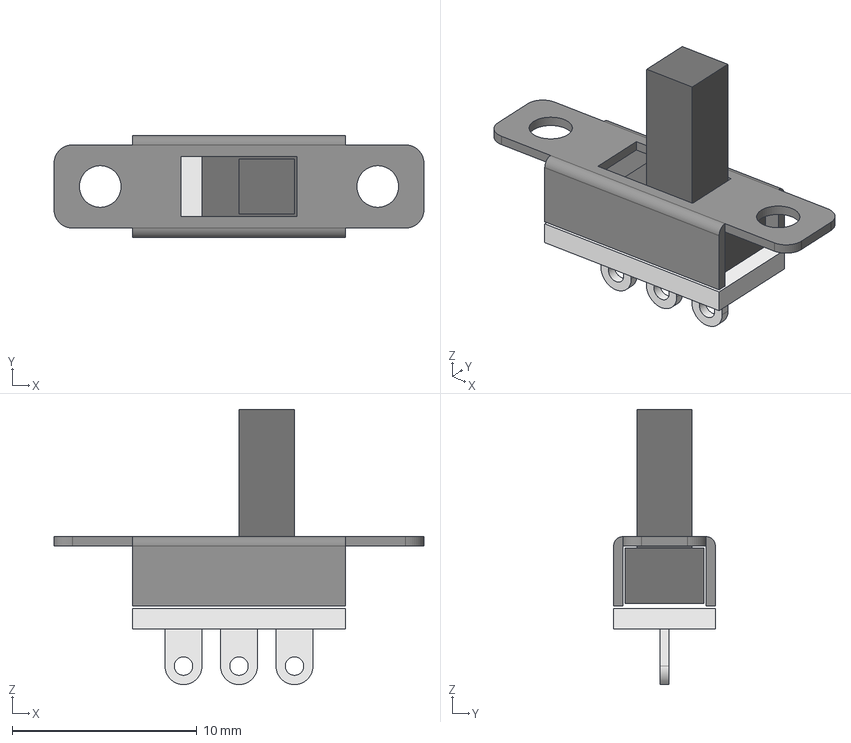
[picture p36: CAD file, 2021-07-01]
3D/parts/slide-switch.fcstd
20.0 x 5.50 x 14.9 mm
handle
board

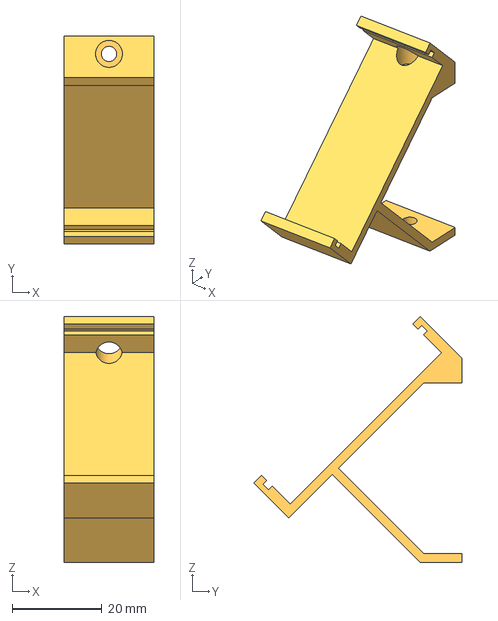
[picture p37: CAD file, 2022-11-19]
3D/board-bracket-compactus.FCStd
20.0 x 46.3 x 54.8 mm

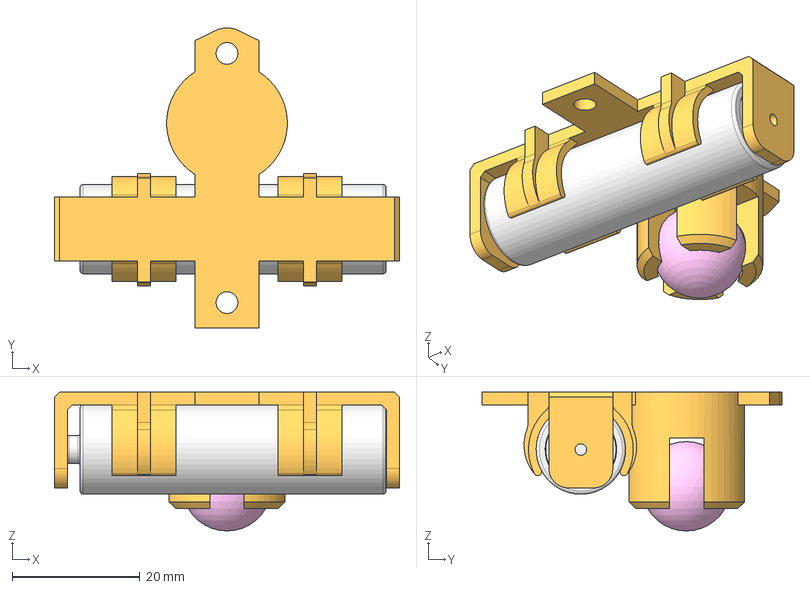
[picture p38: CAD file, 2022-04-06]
3D/ball-caster-battery.FCStd
54.0 x 47.0 x 21.8 mm
Body-ball-caster
ball
AA-Battery

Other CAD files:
3D/wheel-left.FCStd
3D/board-bracket-alternate.FCStd
3D/battery-bracket-kit.FCStd
3D/switch-holder.FCStd
3D/ball-caster-battery.stl
3D/ball-caster.FCStd
3D/ball-caster.stl
3D/battery-bracket-kit.stl
3D/battery-bracket.FCStd
3D/battery-bracket.stl
3D/board-bracket-alternate.stl
3D/board-bracket-compactus.stl
3D/board-bracket.stl
3D/escornaface.FCStd
3D/keypad-cover-sq.FCStd
3D/keypad-cover-sq.stl
3D/keypad-cover.FCStd
3D/keypad-cover.stl
3D/keypad-holder.stl
3D/motor-bracket.FCStd
3D/motor-bracket.stl
3D/ogaki-cpu-holder.FCStd
3D/ogaki-cpu-holder.stl
3D/switch-holder.stl
3D/wheel-left.stl
3D/wheel-right.stl

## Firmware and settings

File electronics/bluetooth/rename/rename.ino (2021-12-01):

/*
 * Tool to rename your HM-10 bluetooth dongle
 * v1.01 - 20211201
 * 
 * 1. Change the name you want for your robot from "ESCORNABOT" to something
 *    different in the first "#define" line of the code.
 * 2. Unplug the VCC wire from the dongle.
 * 3. Upload this Arduino sketch to your Escornabot.
 * 4. Replug the VCC wire to the dongle and restart the Escornabot:
 *    after two seconds, you should see the onboard LED flashing twice
 *    (first check), and after two more seconds, it should flash five more
 *    times if everything went OK (second check).
 * 5. Reflash your Escornabot with its original firmware again (remember to
 *    unplug the VCC wire in the dongle before uploading and reconnect it
 *    after finishing) and enjoy!
 *    (https://www.roboteach.es/escornabot-firmware/)
 */

#define BOTNAME "ESCORNABOT"


/* 
 * >>>>  Rest of the code: DO NOT TOUCH :)  <<<< 
 */
String answer;

void blinkLED(int times) {
  for (int i=0; i<times; i++) {
    digitalWrite(LED_BUILTIN, LOW);
    delay(300);
    digitalWrite(LED_BUILTIN, HIGH);
    delay(100);
  }
  digitalWrite(LED_BUILTIN, LOW);
}

void setup() {
  // initial config
  pinMode(LED_BUILTIN, OUTPUT);
  digitalWrite(LED_BUILTIN, LOW);
  Serial.begin(9600);

  // initial check
  delay(2000);
  Serial.write("AT\r\n");
  answer = Serial.readStringUntil('\n');
  if (answer=="OK\r") {
    blinkLED(2);
    delay(2000);
  } else {
    while (true); // halt
  }

  // change name
  Serial.write("AT+NAME");
  Serial.write(BOTNAME);
  Serial.write(0); // this does the trick to remove CRLF from the name itself for the BT-05!
  Serial.write("\r\n");

  // check answer
  String valid = "+NAME=";
  valid.concat(BOTNAME);
  valid.concat("\r");
  answer = Serial.readStringUntil('\n');
  if (answer==valid) {
    blinkLED(5);
  }
}

void loop() {
}

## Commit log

2020-04-17 initial release
    [ball-caster.FCStd, ball-caster.stl, battery-bracket.FCStd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]
2020-04-17 Keypad cover model and some updates
    [board-bracket.FCStd, board-bracket.stl, keypad-cover.FCStd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]
2020-04-19 First assembly try and other models updates
    [ball-caster.FCStd, battery-bracket.FCStd, board-bracket.FCStd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]
2020-05-16 Fixed constraints to correctly adapt to parametric properties
    [battery-bracket.FCStd]
2020-06-04 Config for ball-caster, aesthetics in battery-bracket
    [ball-caster.FCStd, battery-bracket.FCStd]
2021-06-05 Minor config changes
    [battery-bracket.FCStd, battery-bracket.stl]
2021-06-05 Updated to support 10-16 mm diameter balls
    [ball-caster.FCStd, ball-caster.stl]
2021-06-07 Updated wheels, now with config params.
    [wheel-base.FCStd, wheel-left.stl, wheel-right.stl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]
2021-06-07 small optimization
    [wheel-left.stl, wheel-right.stl, wheels.FCStd]
2021-06-07 config added and small update
    [motor-bracket.FCStd, motor-bracket.stl]
2021-06-08 fixed constrains/config naming
    [ball-caster.FCStd, battery-bracket.FCStd, motor-bracket.FCStd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]
2021-06-08 Added config to board-bracket
    [board-bracket.FCStd, board-bracket.stl]
2021-06-08 Added config to keypad-holder
    [keypad-holder.FCStd, keypad-holder.stl]
2021-06-09 Updated switch-holder
    [switch-holder.FCStd, switch-holder.stl]
2021-06-09 New keypad-cover and renamed keypad-cover with square corners
    [keypad-cover-sq.FCStd, keypad-cover-sq.stl, keypad-cover.FCStd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]
2021-06-24 added cpu holder for ogaki
    [ogaki-cpu-holder.FCStd, ogaki-cpu-holder.stl]
2021-06-30 Added Escornaface. Split wheels in separated files.
    [escornaface.FCStd, wheel-left.FCStd, wheel-right.FCStd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]
2021-07-01 Full Assembly4 added
    [28BYJ-48.FCStd, ball-caster.FCStd, battery-bracket.FCStd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]
2021-07-01 ShapeString automatically centered depending on String content (recompute required)
    [escornaface.FCStd]
2021-07-02 Updated escornaface and assembly
    [28BYJ-48.FCStd, ball-caster.FCStd, battery-bracket.FCStd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]
2021-07-02 Moved LCS to non-customizable step
    [escornaface.FCStd]
2021-07-11 Thinner ball-caster. Removed two screw-hols chamfers.
    [ball-caster.FCStd, ball-caster.stl, motor-bracket.FCStd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]
2021-07-14 Updated orientation. Removed unnecessary screw hole chamfer.
    [battery-bracket.FCStd]
2021-07-14 fixed battery-bracket orientation (again)
    [battery-bracket.FCStd, battery-bracket.stl]
2021-07-14 Fixed motor-bracket orientation
    [motor-bracket.FCStd]
2021-07-14 Fixed keypad-holder orientation
    [keypad-holder.FCStd]
2021-10-16 Updated orientation and assembly
    [28BYJ-48.FCStd, ball-caster.FCStd, ball-caster.stl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]
2021-10-16 hide LCS's
    [driver-board.FCStd]
2021-11-20 Added Fritzing connections schematic
    [connections.fzz]
2021-11-30 Electronics reorganization
    [connections.fzz]
2021-11-30 Added Bluetooth Low Energy info
    [bluetooth.fzz]
2021-11-30 moved files
    [connections.fzz]
2022-03-12 New board bracket for most common mini-breadboard with notches
    [board-bracket-alternate.FCStd, board-bracket-alternate.stl]
2022-03-12 Updated switch holder position to ease battery swapping
    [ball-caster.FCStd, escornabot.FCStd, switch-holder.FCStd]
2022-03-19 New battery-bracket-kit to support Escornabot-Pintor-kit
    [battery-bracket-kit.FCStd, battery-bracket-kit.stl]
2022-03-25 Added ball-caster to supoort fifth rechargable battery
    [ball-caster-battery.FCStd, ball-caster-battery.stl]
2022-04-06 Added structural supports for ball-caster-battery
    [ball-caster-battery.FCStd, ball-caster-battery.stl]
2022-11-19 New battery bracket for the compactus (PCB) version
    [board-bracket-compactus.FCStd, board-bracket-compactus.stl]
2022-12-18 Updated some holes and tolerances
    [battery-holder-2x2.FCStd, board-bracket-alternate.FCStd, board-bracket-alternate.stl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]
